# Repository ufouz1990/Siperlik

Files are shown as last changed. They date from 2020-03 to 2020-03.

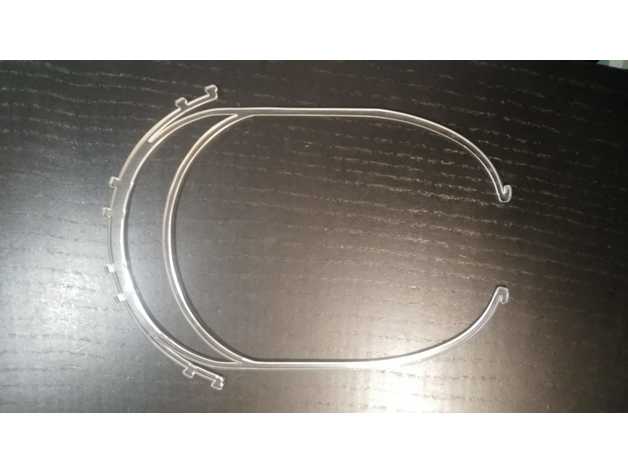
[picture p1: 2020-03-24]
Varyasyon_2/images/WhatsApp_Image_2020-03-22_at_20.31.49.jpeg

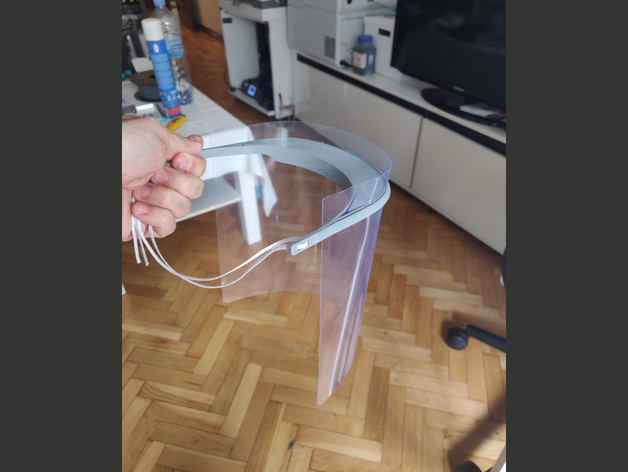
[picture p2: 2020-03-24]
Varyasyon_1/images/StrapLock2.png

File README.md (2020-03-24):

# Açıklama
Bu repo, sağlık personellerini korumaya yönelik hazırlanan siperlik tasarımlarını ve bilgilerini içerir.

#3BoyutluDestek
Ekip olarak geliştirdiğimiz tasarımlar
	#2S:
	Yüzkalkanı2Saat adı altında paylaşılan model
	#3BD:
	3BoyutluDestek adı altında paylaşılan model
	#RT2
	RT2 adı altında paylaşılan model.
	
	#Versiyonlama Şekli
	- Telegram grubumuzun dosyalarında paylaşılan son dosyaları indirerek onlara v1.0 adını koydum.
	gelecekte yapılacak güncellemeleri de bu versiyonlama uyarak v1.0 v1.1 diye adlandıracağız.
	Sonsuza kadar ".son .sonson .buseferson .dahason" diye gidemeyiz.
	
	- Küçük değiştirmelerde (örn: baskı hızını arttırmaya ya da desteksiz basmaya yönelik ufak değişiklikler) v1.1 > v1.2 şeklinde atlamalar yapılacak.
	- Tasarımsal değişiklik gibi büyük değişikliklerde (Örn: Lastik bağlama şeklinin değiştirilmesi, asetat tutturmanın değiştirilmesi gibi) v1.0 > v2.0 şeklinde atlama yapılacak.
	
	- Tasarımcı / geliştirici yeni bir versiyon çıkardığında yaptığı değişikliği bize bildirecek. böylece onu "Changelog" altına koyacağız. Ne yapıldı bileceğiz.
	- Dosyanın farklı Nozzle tipleri için farklı tipleri varsa ancak bu değişiklik dosyada bir yenilik getirmiyorsa "DosyaAdi_NozzleOlcusu_Versiyon.stl" şeklinde adlandırma yapılacak.
	
#Varyasyon 1 / 2
Thingverse sitesinden bulunan alternatif maske önerileri

#PRUSA Original
Prusa 3D yazıcı firmasının geliştirdiği orijinal tasarım

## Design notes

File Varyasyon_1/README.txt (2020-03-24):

V1 = Easy 3D printed Face Shield by HanochH on Thingiverse: https://www.thingiverse.com/thing:4233193
V1.1 = Covid-19 Face Shield with temples fast/simple version to cut in Laser Acrylic or 3D print  by racl on Thingiverse: https://www.thingiverse.com/thing:4236612

V1.1 Changelog = Added pins to lock elastic strap in place, allowing easy adjustment, with no need of sewing.
Made 1mm longer so A4 foil is a bit easier to set in place.

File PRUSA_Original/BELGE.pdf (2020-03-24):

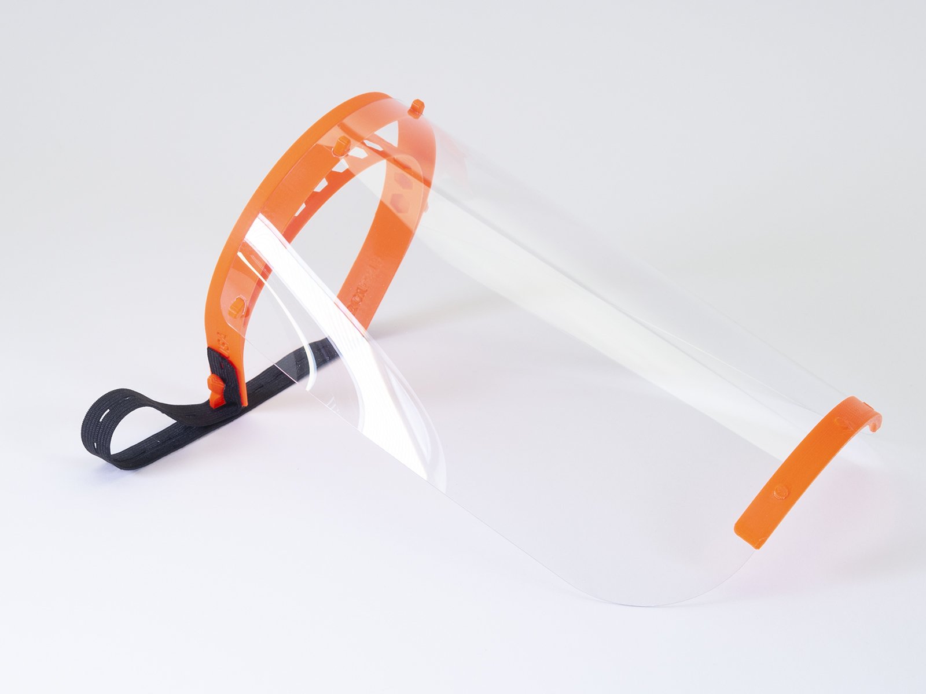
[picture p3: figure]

## Summary

A prototype face shield that we developed. In three days, we went through dozens of prototypes and two verifications with the Czech Ministry of Health.

Version RC2 Changes from RC1:

Increased wall thickness (slightly stiffer and more durable)
Inner wall from 1.5 mm to 2 mm
Outer wall from 2 mm to 2.5 mm
The headband is no longer printed compressed - Lower pressure on the temple
The visor was moved further away from the forehead - This allows a better fit over bigger respirators and protective goggles
The printed part now has an extension for the visor (the visor curves less than the headband).

For now, both RC1 and RC2 versions are relevant. RC1 lets you fit more printed parts on a single print bed. However, if maximum yield isn’t the priority, RC2 provides slightly better protection and is more comfortable to

Prusa Research (https://www.prusaprinters.org/social/16/prints)

## Prusa Protective Face Shield - RC2

VIEW IN BROWSER (https://www.prusaprinters.org/prints/25857-prusa-protective-face-shield-rc2)

updated 23. 3. 2020 | published 20. 3. 2020

•
◦
◦
•

•

•

wear.

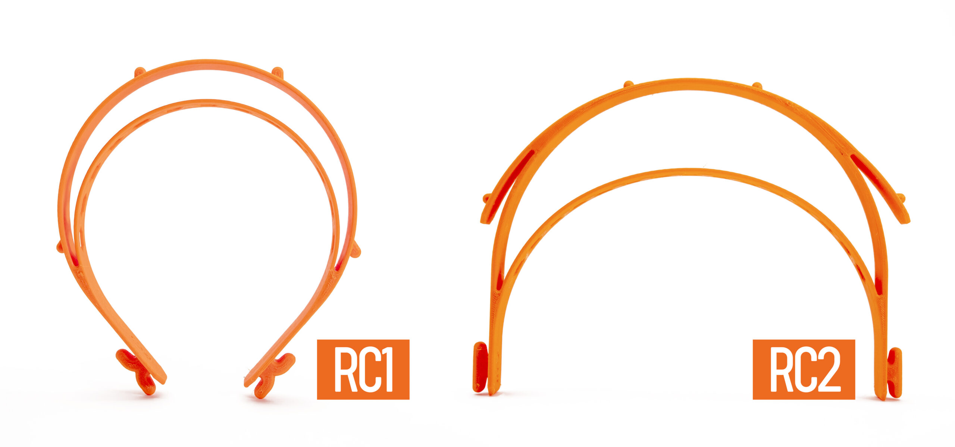
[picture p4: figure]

If you want to manufacture shields for others PLEASE READ THIS CAREFULLY

Act as if you were infected by the COVID-19 virus. Wear a face mask and a fresh pair of gloves when collecting each batch of printed parts. Store the parts immediately in a sealable bag.
Talk with whoever you’re making the shields for, let them know about your manufacturing environment
There is still debate about how long the virus survives on plastic, but most sources mention 2-3 days. That means that by letting the packed face shields sit for 2-3 days before distributing them, you’ll greatly reduce risk of transmission
Do not store the entire stock in one place, minimize the risk of cross contamination

More information: https://blog.prusaprinters.org/from-design-tomass-3d-printing-of-medical-shields-in-three-days/ (https://blog.prusaprinters.org/from-design-to-mass-3d-printing-of-medical-shields-in-three-days/)

Assembly manual: English version (https://manual.prusa3d.com/Guide/Prusa+Face+Shield/1527) English Community version using a laminating foil (https://manual.prusa3d.com/Guide/Assembling+the+Prusa+Face+Shield+-+community+version/1528#s41280) Czech version (https://manual.prusa3d.com/Guide/Prusa+Oblicejovy+Stit/1526)

Video:

"https://www.youtube.com/embed/pP7z3iw76GA"

Rubber band You can either use a thicker one and make a hole in it at each end (make at least 10 mm cut) or use a thin one and tie it to both ends of the shield.

Visor / front plate

•

•

•

•

•

5.91 hrs

1 pcs

f

0.25 mm

k

0.40 mm

h

8

105.00 g

d

MK3/S

Print Files (.gcode) | DOWNLOAD ALL FILES (https://www.prusaprinters.org/prints/25857-prusa-protective-face-shield-rc2/files)

10.9 MB

- 5.91 hrs f 0.25 mm k 0.40 mm h PET | 105.20 g d MK3/S
updated 22. 3. 2020 | (https://www.prusaprinters.org/prints/25857-prusa-protective-face-shield-rc2/files)
Model Files (.stl, .3mf, .obj, .amf) | DOWNLOAD ALL FILES (https://www.prusaprinters.org/prints/25857-prusa-protective-face-shield-rc2/files)

287.6 KB
updated 22. 3. 2020 | (https://www.prusaprinters.org/prints/25857-prusa-protective-face-shield-rc2/files)

there is a DXF drawing in the file section (and an alternative longer version)
the holes can be made with a standard office hole puncher
we used 0.5 mm thick petg sheet (Covestro VIVAK), but you should be able to use any clear laser cuttable plastic with similar thickness.

Visor PDF drawings Normal size (http://prusa3d.com/downloads/others/COVID19_SHIELD_FOIL.pdf) Extended version (dentists) (http://prusa3d.com/downloads/others/COVID19_SHIELD_FOIL_LONG.pdf)

Licence and selling of face shields We share these files under noncommerical licence. It would be great if you donated these shields to those in need for free. If you need to cover your production costs, we are ok with you selling the shields for production cost. However, we do not want to see these shields on eBay for $50.

Healthcare (https://www.prusaprinters.org/prints?categoryId=87) > Accessibility (https://www.prusaprinters.org/prints?categoryId=88)

Supports are not necessary. Print with at least 3 perimeters, about 30% infill.

Ideally, print it from PETG.

•
•

rc2_covid19__2pcs_025mm_petg_mk3s_5h54m.gcode (https://www.prusaprinters.org/prints/25857-prusa-protective-face-shield-rc2/files)

covid19_headband_rc2_2pcs.3mf

290.5 KB
updated 22. 3. 2020 | (https://www.prusaprinters.org/prints/25857-prusa-protective-face-shield-rc2/files)

662.6 KB
updated 22. 3. 2020 | (https://www.prusaprinters.org/prints/25857-prusa-protective-face-shield-rc2/files)

284.2 KB
updated 22. 3. 2020 | (https://www.prusaprinters.org/prints/25857-prusa-protective-face-shield-rc2/files)

585.1 KB
updated 22. 3. 2020 | (https://www.prusaprinters.org/prints/25857-prusa-protective-face-shield-rc2/files)

383.1 KB
updated 22. 3. 2020 | (https://www.prusaprinters.org/prints/25857-prusa-protective-face-shield-rc2/files)

3.9 KB
updated 22. 3. 2020 | (https://www.prusaprinters.org/prints/25857-prusa-protective-face-shield-rc2/files)

300.2 KB
updated 23. 3. 2020 | (https://www.prusaprinters.org/prints/25857-prusa-protective-face-shield-rc2/files)

## License

This work is licensed under a
Creative Commons (4.0 International License)

Attribution-NonCommercial (http://creativecommons.org/licenses/by-nc/4.0/)

covid19_headband_rc2_1pcs.3mf

covid19_headband_rc2.stl

covid19-shield.3mf

covid19_headband_rc1.stl

bottom_reinforcement.stl

shield_final.dxf

shield_longer_version.dxf

✖ | Sharing without ATTRIBUTION
✔ | Remix Culture allowed
✖ | Commercial Use
✖ | Free Cultural Works
✖ | Meets Open Definition

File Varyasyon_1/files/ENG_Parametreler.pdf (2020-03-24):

- BASKI PARAMETRELERI
- Nozzle Diameter: 0.4mm
- Layer Height: 0.28mm
- Fill: 50%
- Fill Type: Grid
- Upper Layers: 4
- Lower Layers: 2
- Flow: 80%
- Without supports
- PRINTING SPEED
- Perimeters : 80mm / s
- Small perimeters: 80mm / s
- External perimeters: 80mm / s
- Fill: 80mm / s
- Solid fill: 80mm / s
- Top solid fill: 80mm / s
- Bridges: 80mm / s
- Fill: 80mm / s
- Travel: 180mm / s

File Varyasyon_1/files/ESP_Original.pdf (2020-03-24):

# Manual de impresión y ensamblaje mascara protectora

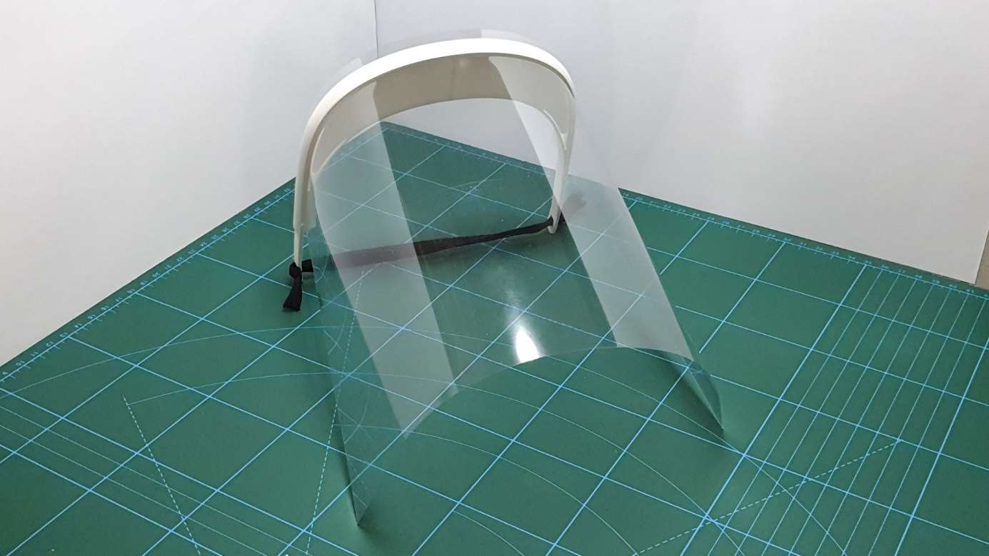
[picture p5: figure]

Página: 2/14

Página: 3/14

# Datos del Documento

Autor: | @YKA3D
Revisor: | @kermithenson
Fecha de publicación: | 18/03/2020
Observaciones:
Para comenzar a fabricar es necesario que la máquina esté correctamente calibrada. Una vez calibrada, se deberá llevar a cabo una prueba de tolerancia.

Test: https://www.thingiverse.com/thing:1662342

# Hoja de Cambios

Fecha | Versión | Autor | Cambios
18 de marzo de 2020 | v.0.1 | @YKA3D | Creación del documento
18 de marzo de 2020 | V.0.3 | @kermithenson | Modificación protocolos
20 de marzo de 2020 | V.0.9 | @YKA3D | Actualizaciones varias

# Versión STL

Fecha | Versión | Autor | Cambios
20 de marzo de 2020 | v.0.3 | @Hanochh | Creación STL mascara

Página: 4/14

# Índice

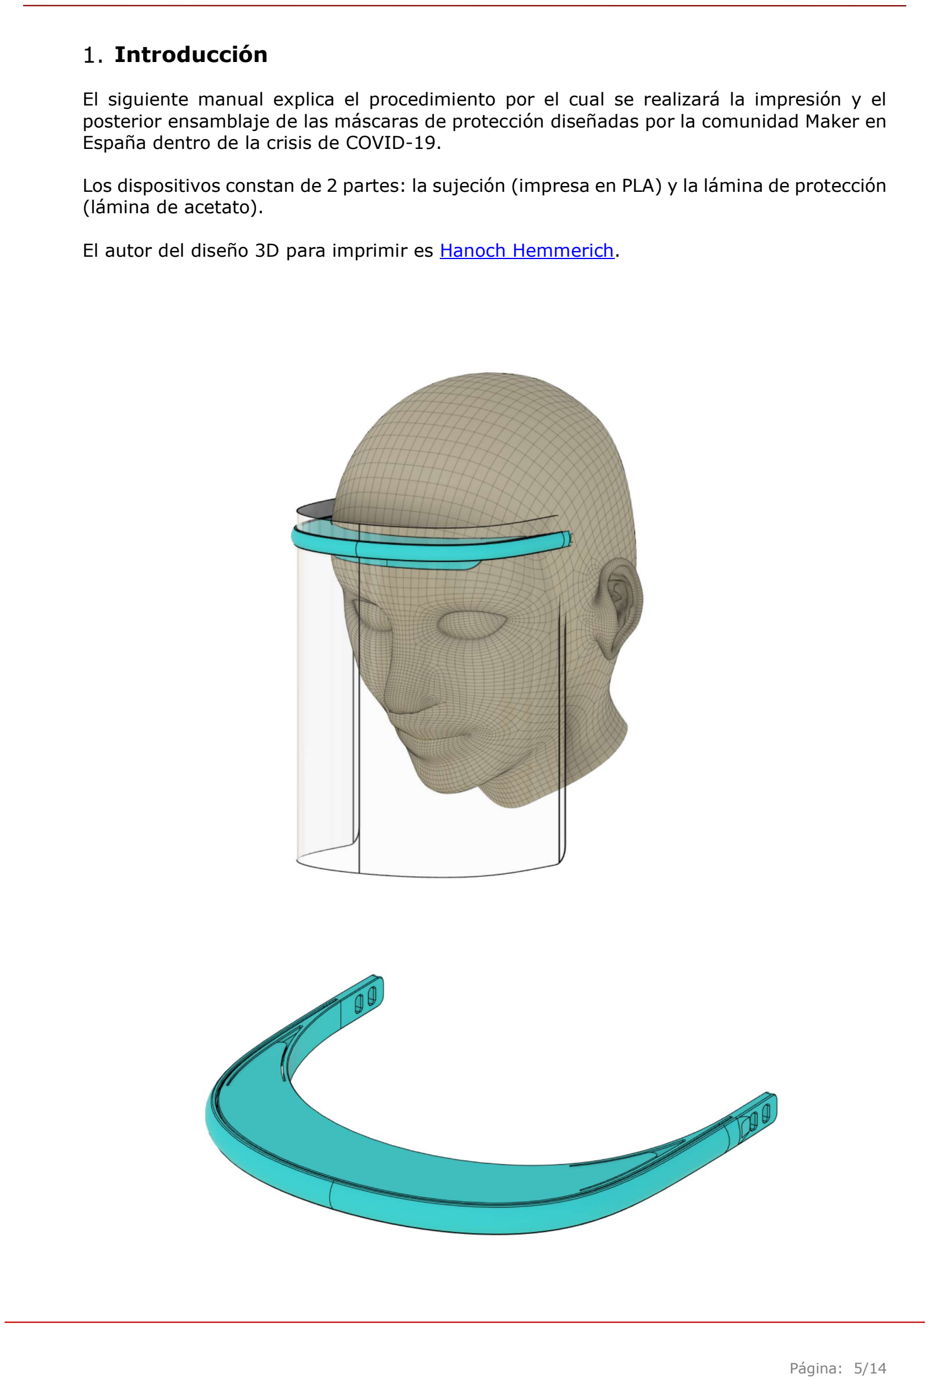
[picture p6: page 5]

Página: 5/14

### Introducción

El siguiente manual explica el procedimiento por el cual se realizará la impresión y el posterior ensamblaje de las máscaras de protección diseñadas por la comunidad Maker en España dentro de la crisis de COVID-19.

Los dispositivos constan de 2 partes: la sujeción (impresa en PLA) y la lámina de protección (lámina de acetato).

El autor del diseño 3D para imprimir es Hanoch Hemmerich.

Página: 6/14

### Enlace de compras

Los siguientes enlaces solo son una referencia del material utilizado para la elaboración de las pantallas protectoras.

- Láminas de encuadernar
o 180 micras
https://www.amazon.es/Fellowes-Cristal-Portadas-encuadernaci%C3%B3ntransparente/dp/B002BARBEK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
o 240 micras
https://www.amazon.es/gp/product/B000YC1UWG/ref=ppx_yo_dt_b_asin_title_o00_s00?ie=UTF8&psc=1
- Goma elástica
https://www.amazon.es/Banda-el%C3%A1stica-personalizada-Artesan%C3%ADametros/dp/B0749M5CBF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

### Parámetros de impresión

El archivo para su impresión se puede descargar desde el siguiente enlace:

Enlace de descarga

Los parámetros de impresión solo son una guía de referencia cada uno conoce bien su máquina y los límites de esta:

- Diámetro del Nozzle: 0.4mm
- Altura de capa: 0.28mm
- Relleno: 50%
- Tipo de relleno: Rejilla
- Capas superiores: 4
- Capas inferiores: 2
- Flujo: 80%
- Sin soportes
- Velocidad de impresión:
o Perímetros: 80mm/s
o Perímetros pequeños: 80mm/s o Perímetros externos: 80mms/s o Relleno: 80mms/s
o Relleno solido: 80mms/s
o Relleno solido superior: 80mm/s o Puentes: 80mm/s
o Relleno: 80mm/s
o Recorrido: 180mm/s

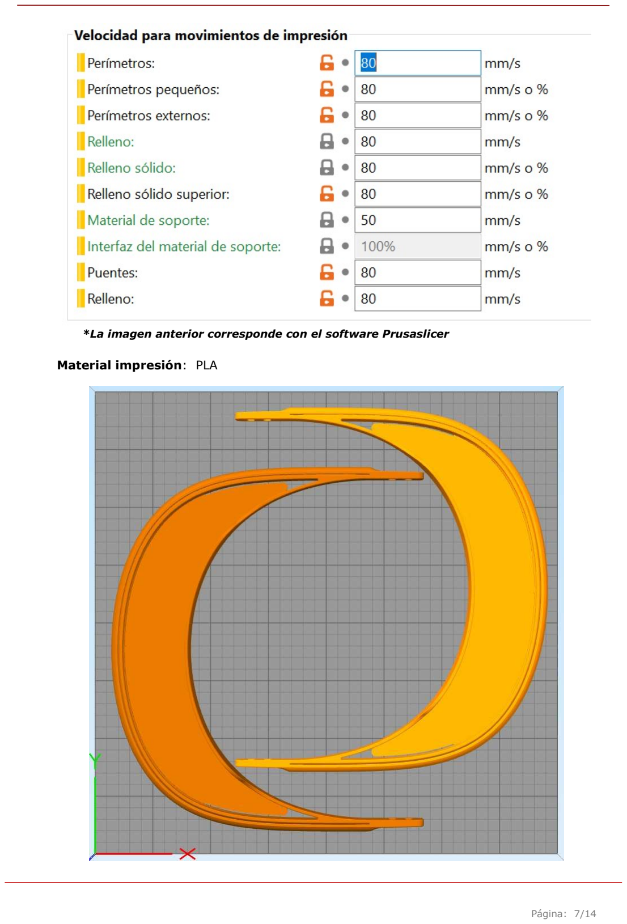
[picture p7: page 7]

Página: 7/14

*La imagen anterior corresponde con el software Prusaslicer

Material impresión: PLA

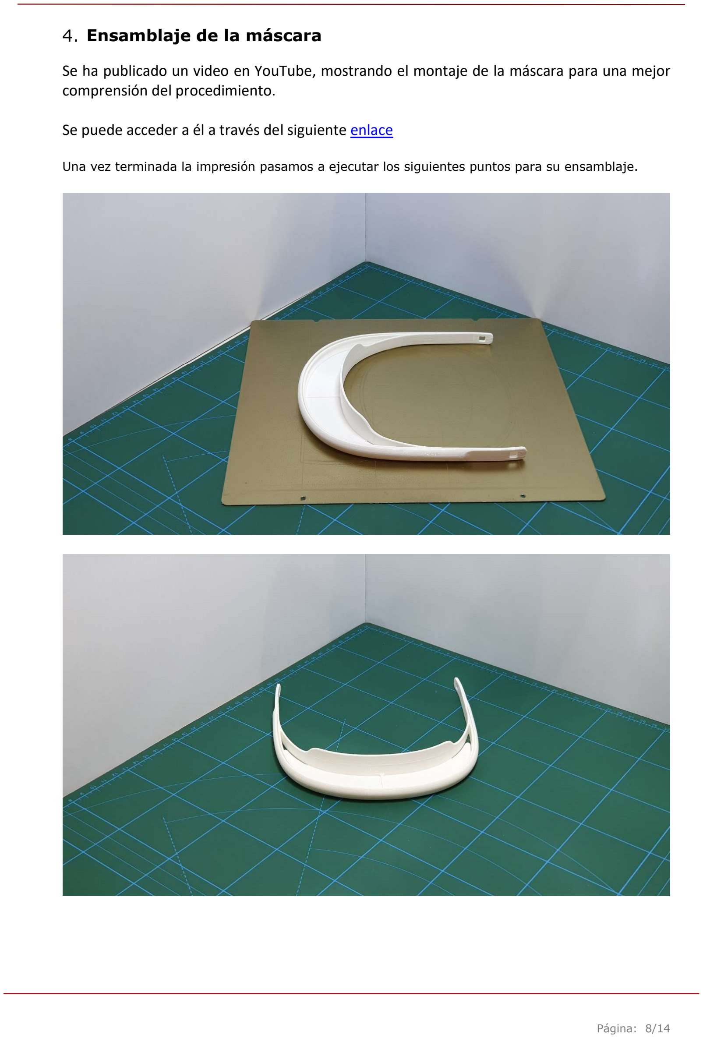
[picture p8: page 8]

Página: 8/14

### Ensamblaje de la máscara

### Se ha publicado un video en YouTube, mostrando el montaje de la máscara para una mejor

comprensión del procedimiento.

### Se puede acceder a él a través del siguiente enlace

Una vez terminada la impresión pasamos a ejecutar los siguientes puntos para su ensamblaje.

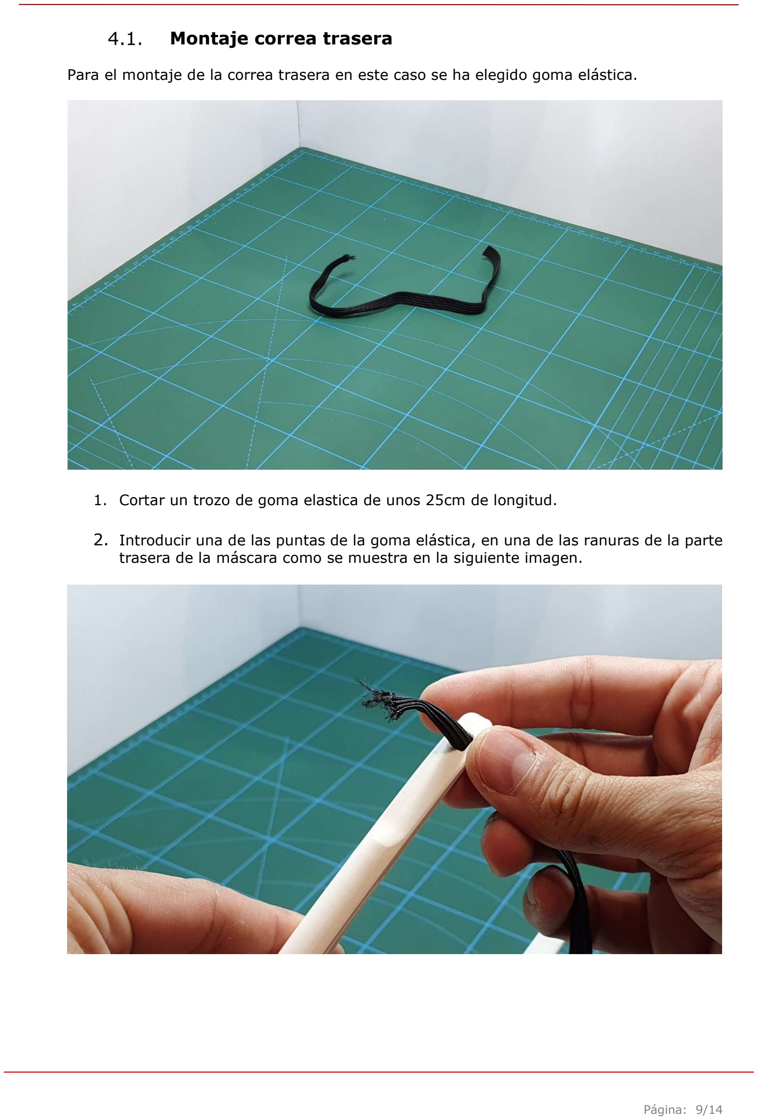
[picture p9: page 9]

Página: 9/14

### Montaje correa trasera

Para el montaje de la correa trasera en este caso se ha elegido goma elástica.

1. Cortar un trozo de goma elastica de unos 25cm de longitud.

### 2. Introducir una de las puntas de la goma elástica, en una de las ranuras de la parte

trasera de la máscara como se muestra en la siguiente imagen.

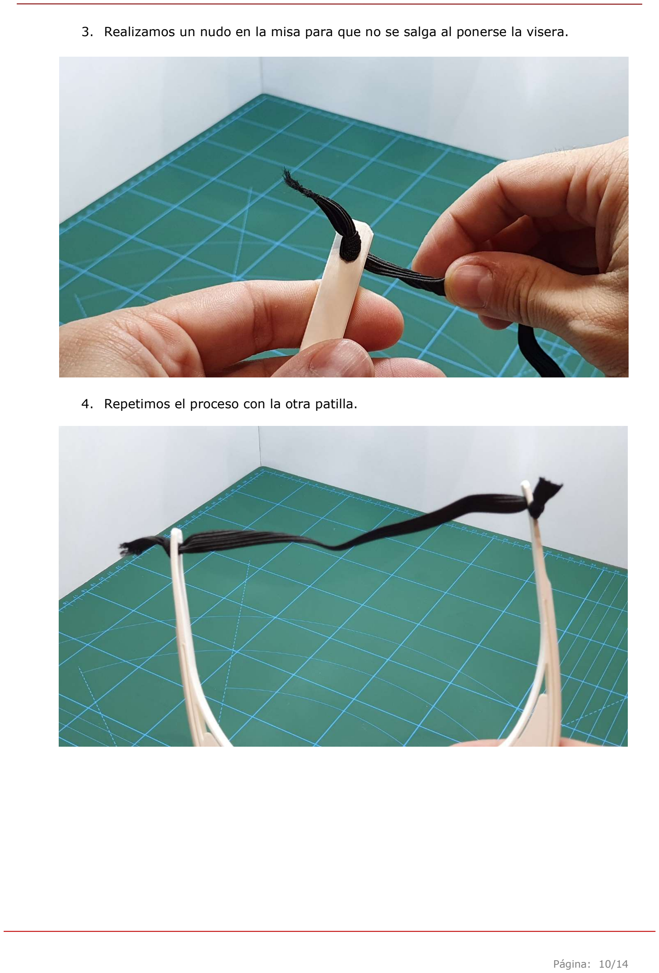
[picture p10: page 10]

Página: 10/14

3. Realizamos un nudo en la misa para que no se salga al ponerse la visera.
4. Repetimos el proceso con la otra patilla.

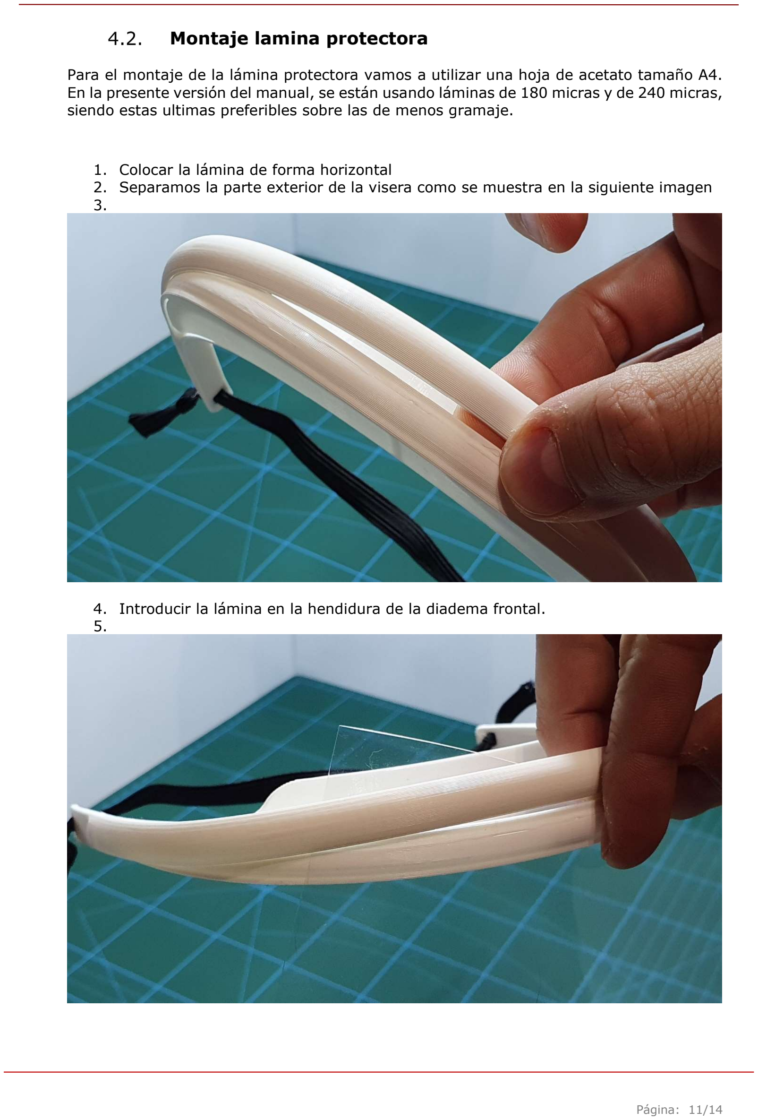
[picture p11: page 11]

Página: 11/14

### Montaje lamina protectora

Para el montaje de la lámina protectora vamos a utilizar una hoja de acetato tamaño A4. En la presente versión del manual, se están usando láminas de 180 micras y de 240 micras, siendo estas ultimas preferibles sobre las de menos gramaje.

### 1. Colocar la lámina de forma horizontal 2. Separamos la parte exterior de la visera como se muestra en la siguiente imagen

3.

4. Introducir la lámina en la hendidura de la diadema frontal. 5.

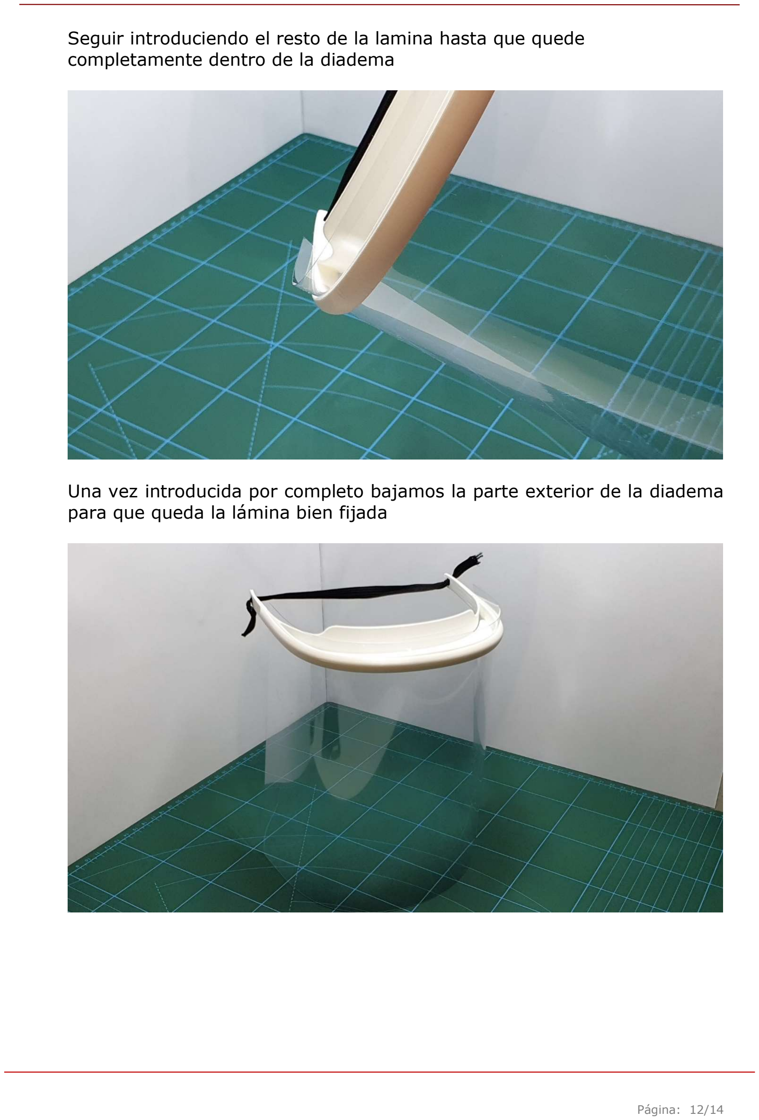
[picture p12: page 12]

Página: 12/14

### Seguir introduciendo el resto de la lamina hasta que quede completamente dentro de la diadema

### Una vez introducida por completo bajamos la parte exterior de la diadema para que queda la lámina bien fijada

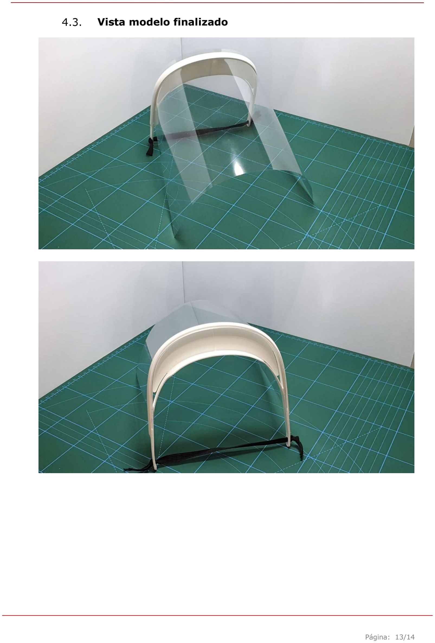
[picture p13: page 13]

Página: 13/14

### Vista modelo finalizado

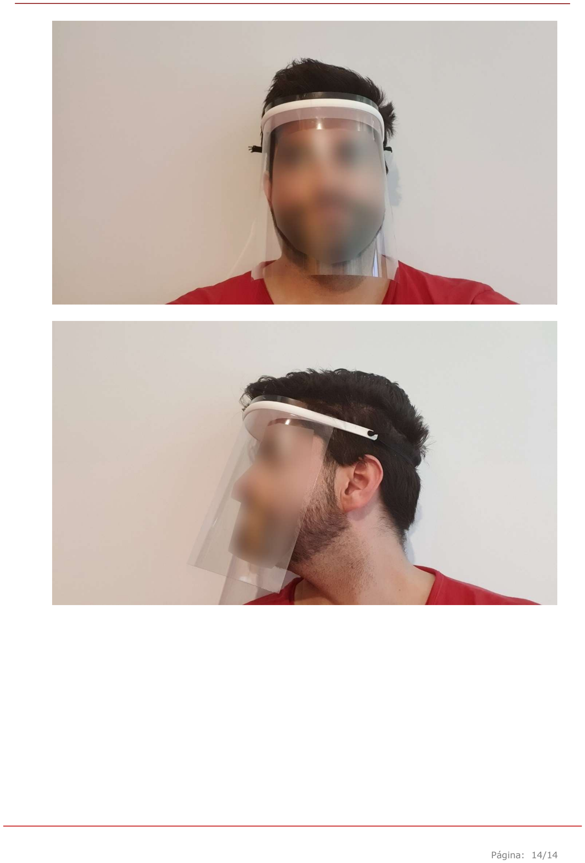
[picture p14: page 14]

Página: 14/14

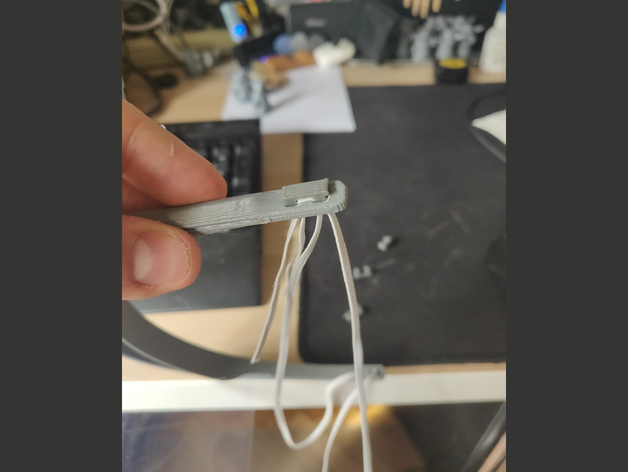
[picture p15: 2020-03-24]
Varyasyon_1/images/StrapLock1.png

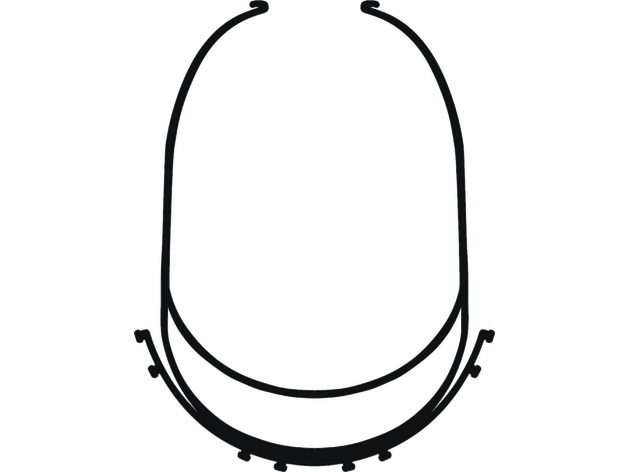
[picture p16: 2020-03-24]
Varyasyon_2/images/face_shiled_with_stems.jpg

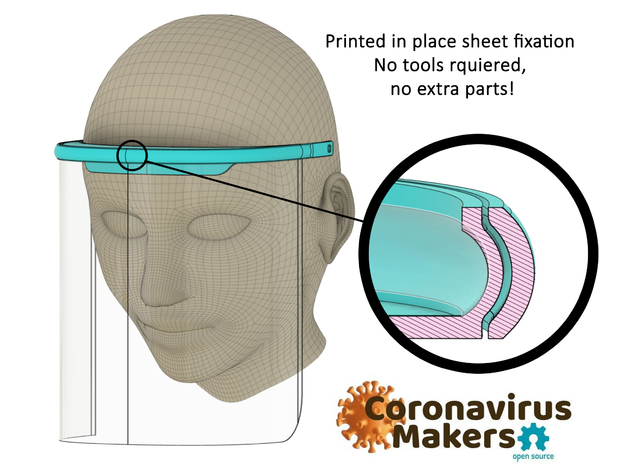
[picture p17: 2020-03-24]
Varyasyon_1/images/plana_2.jpg

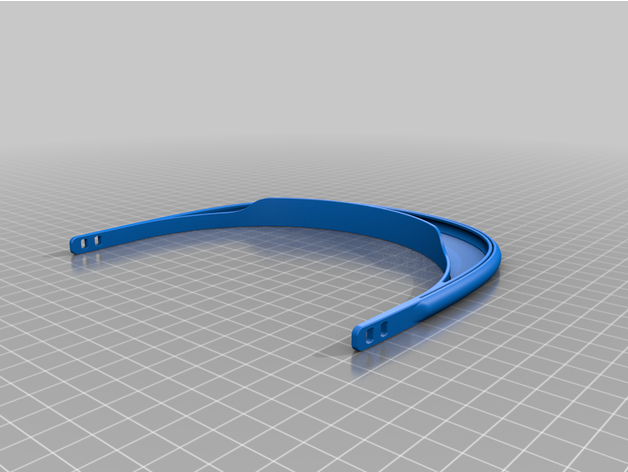
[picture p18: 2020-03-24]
Varyasyon_1/images/Visera_Plana_con_cierre_y_ventilacion_0.5.png

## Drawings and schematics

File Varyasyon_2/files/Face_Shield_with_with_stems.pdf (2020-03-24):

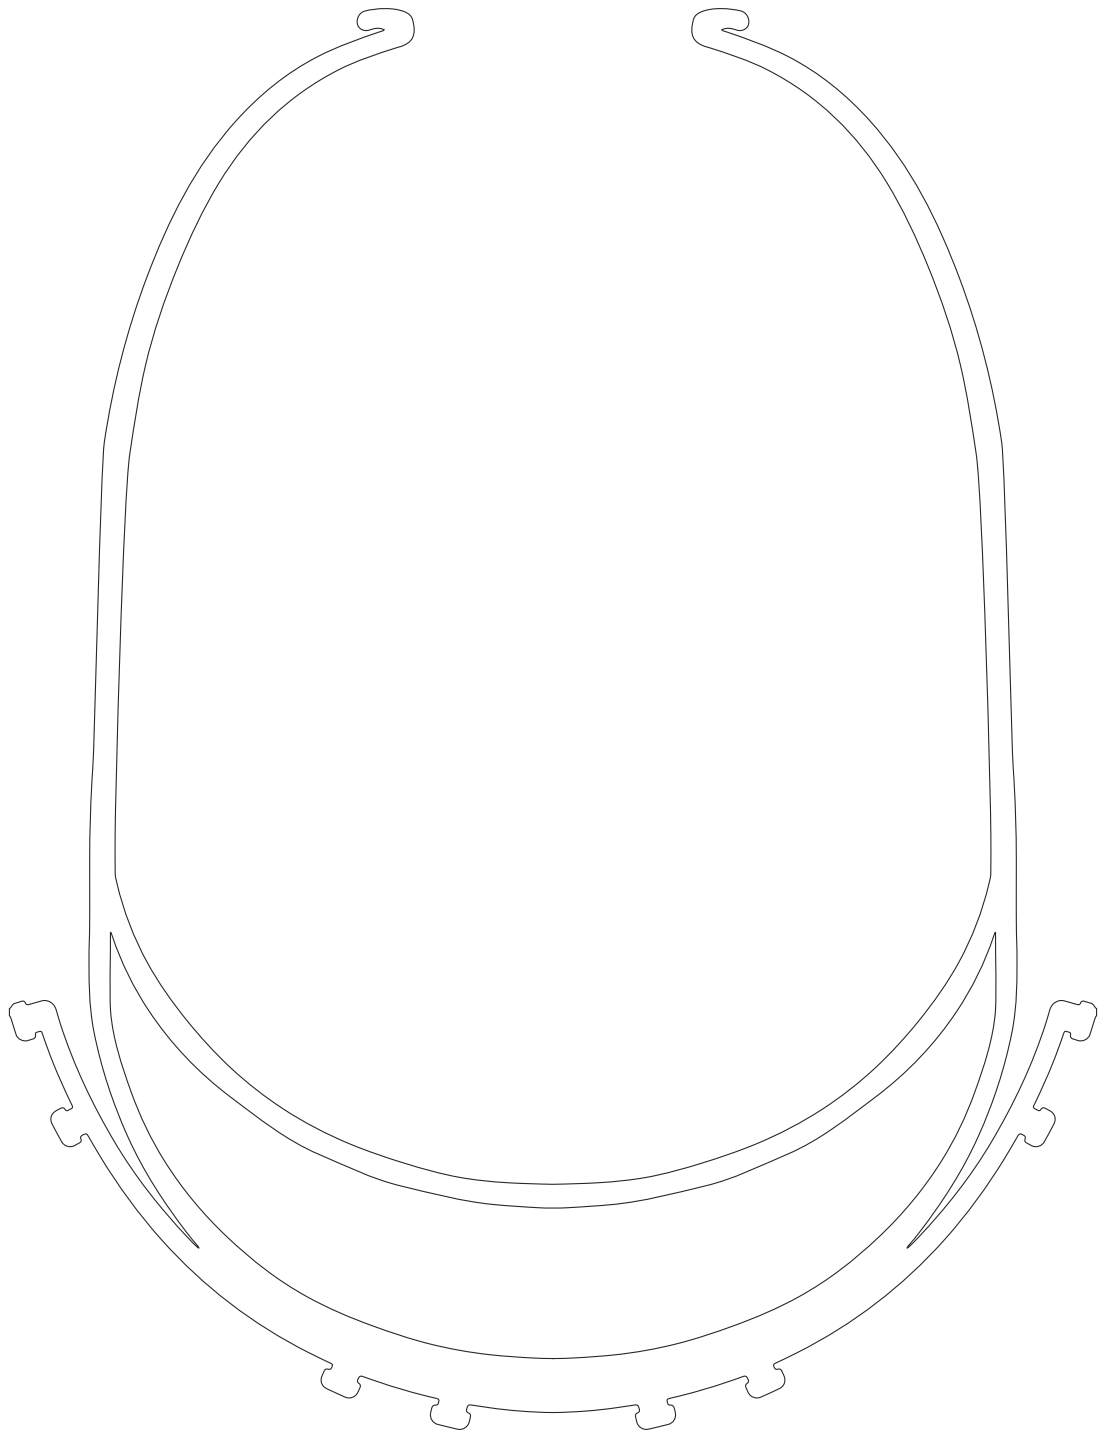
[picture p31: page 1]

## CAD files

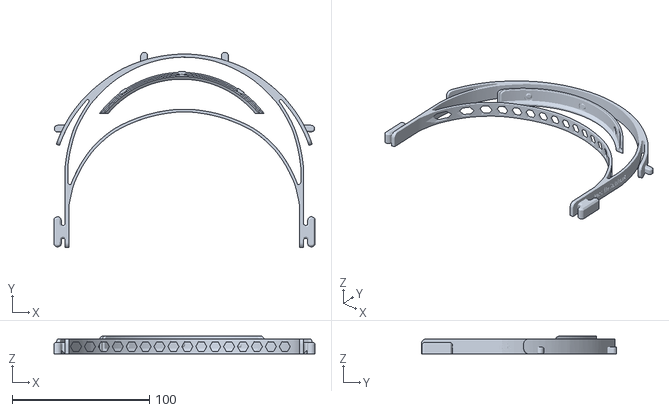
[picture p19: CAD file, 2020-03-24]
3BoyutluDestek/2S/YK_v1.0.stl
190.2 x 142.5 x 13.0

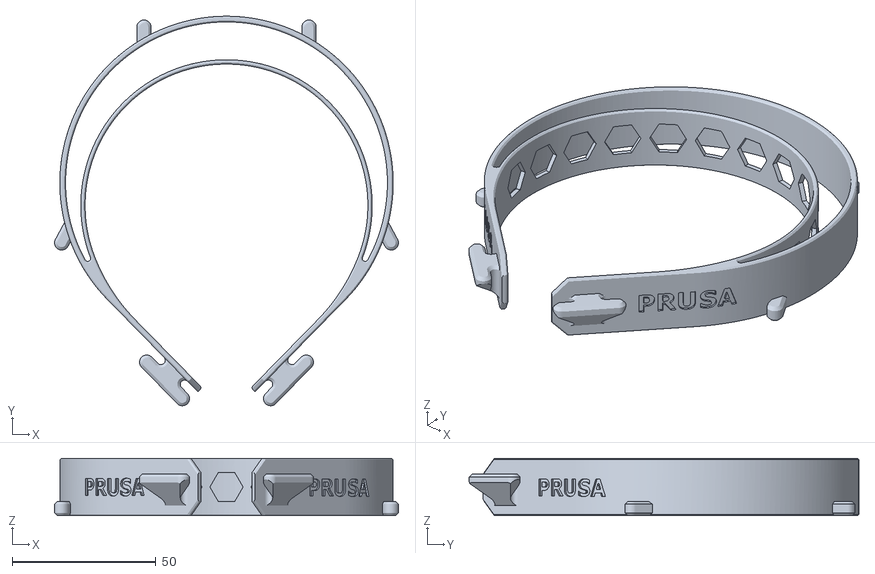
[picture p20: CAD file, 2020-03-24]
PRUSA_Original/covid19_headband_rc1.stl
119.7 x 135.6 x 20.0

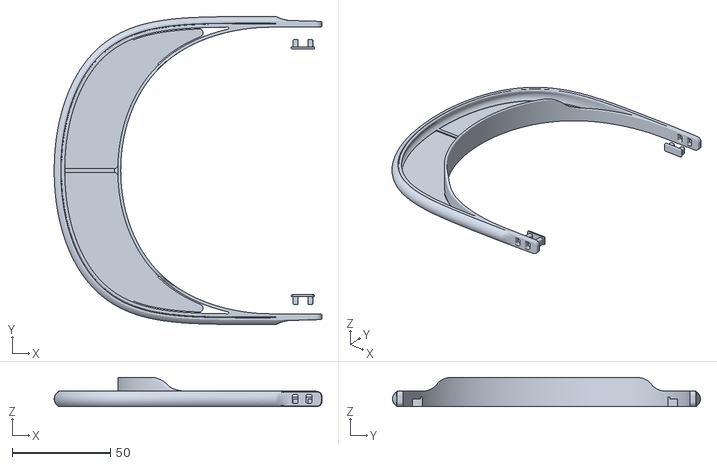
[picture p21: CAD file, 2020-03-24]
Varyasyon_1/files/Varyasyon_1.1.stl
136.3 x 156.8 x 15.0

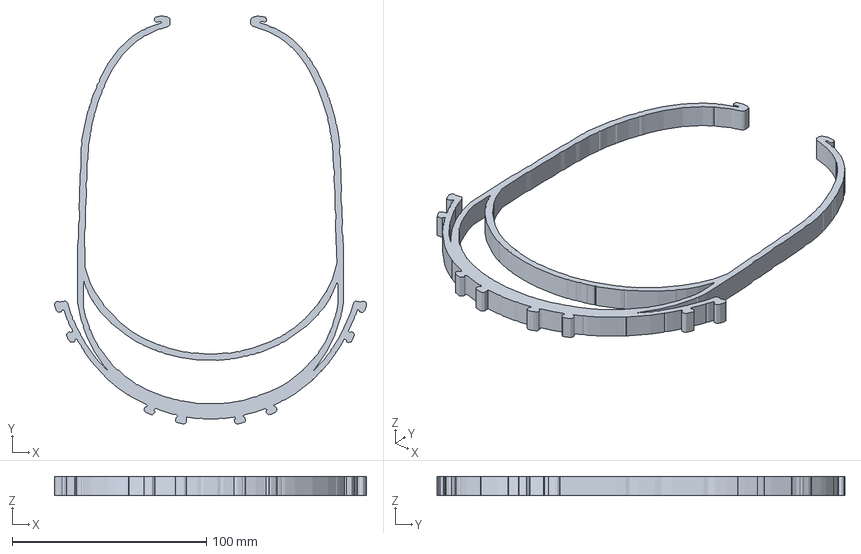
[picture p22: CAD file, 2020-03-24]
Varyasyon_2/files/face_shiled_with_stems.3mf
160.5 x 209.8 x 10.0 mm

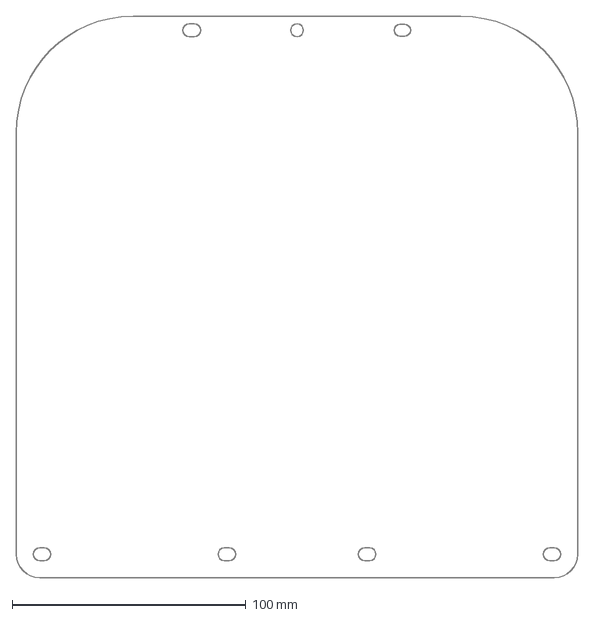
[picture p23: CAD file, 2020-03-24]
3BoyutluDestek/2S/Shield_A3_v1.0.dxf
240.0 x 240.0 mm

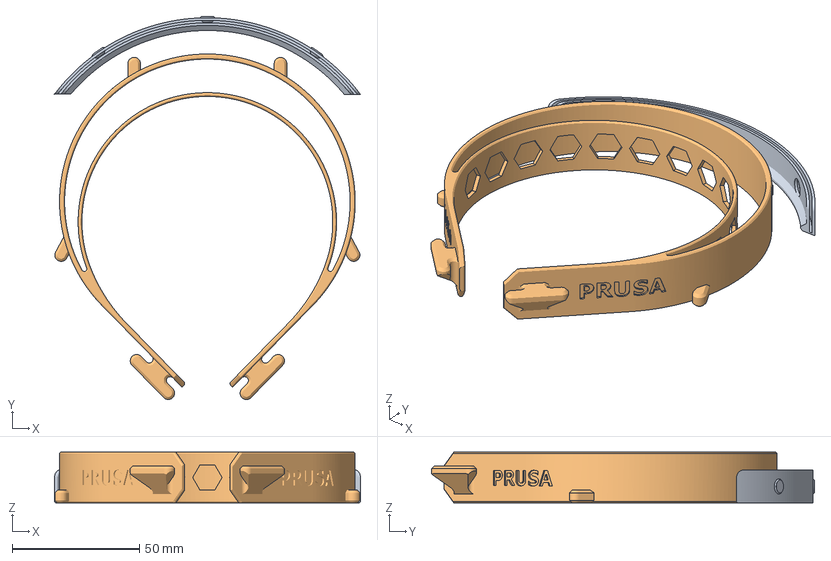
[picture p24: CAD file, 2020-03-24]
PRUSA_Original/covid19-shield.3mf
120.1 x 150.3 x 20.0 mm
reinforcement_final.stl
COVID19_SHILED_R1 (1).stl

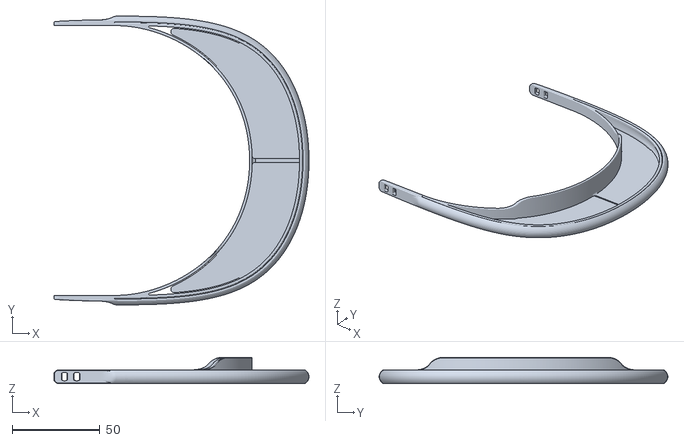
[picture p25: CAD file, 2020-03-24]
Varyasyon_1/files/Varyasyon_1.stl
145.6 x 164.8 x 15.0

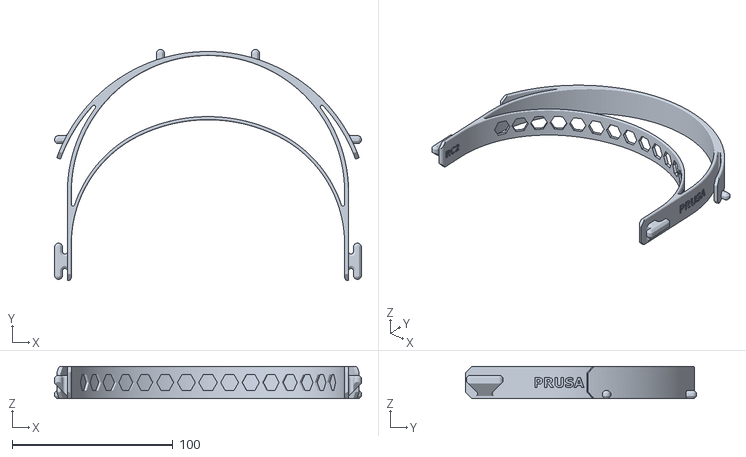
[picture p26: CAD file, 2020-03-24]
PRUSA_Original/covid19_headband_rc2.stl
191.0 x 143.8 x 20.0

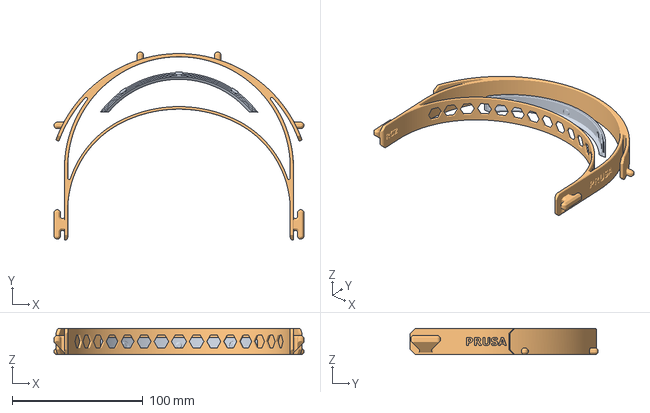
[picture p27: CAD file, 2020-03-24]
PRUSA_Original/covid19_headband_rc2_1pcs.3mf
191.0 x 143.8 x 20.0 mm
reinforcement_final.stl
COVID19_SHIELD_RC2.stl

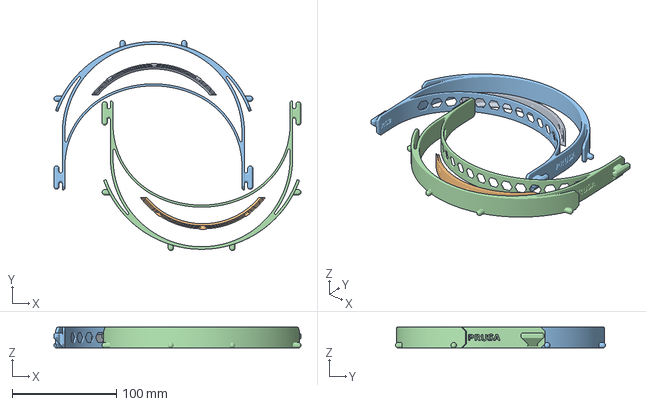
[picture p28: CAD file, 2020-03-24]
PRUSA_Original/covid19_headband_rc2_2pcs.3mf
237.2 x 202.0 x 20.0 mm
reinforcement_final.stl
COVID19_SHIELD_RC2.stl

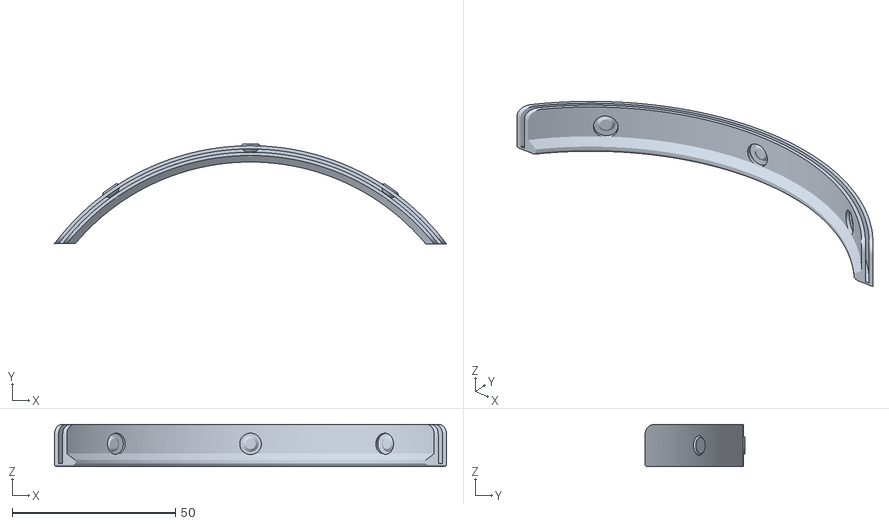
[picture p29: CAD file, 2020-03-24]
PRUSA_Original/bottom_reinforcement.stl
120.1 x 30.6 x 13.0

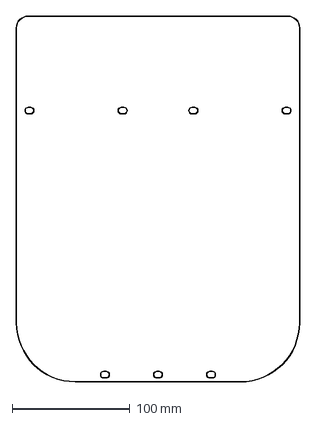
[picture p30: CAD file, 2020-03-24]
PRUSA_Original/shield_longer_version.dxf
240.0 x 310.0 mm

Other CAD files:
3BoyutluDestek/3BD/3BD_v1.0.stl
Varyasyon_2/files/face_shiled_with_stems.dxf
Varyasyon_2/files/face_shiled_with_stems.stl
